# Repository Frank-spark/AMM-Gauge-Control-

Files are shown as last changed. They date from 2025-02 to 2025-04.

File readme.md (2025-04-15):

---
## **Project: ESP32 Gauge Control with H2 Integration**

### **Overview**
This project controls an **analog gauge** and **H2 power supply** using an **ESP32-WROOM-32D**. The gauge reflects the **fill level of a tank** based on readings from a **resistance-based float sensor (240Ω - 30Ω)**. The system implements a **soft-start feature** for H2 power supplies to prevent inrush current, and includes a **web configuration interface** for easy parameter adjustment.

### **Features**
✔ Reads **float sensor resistance** and converts it to gauge display using **PWM control**  
✔ **Smooths the gauge movement** to prevent needle shaking  
✔ **Blinks a backlight** when the fill level is low  
✔ **Soft-start control** (0-5V ramping) for H2 power supplies  
✔ **H2 signal detection** from existing H2 board  
✔ Uses **noise-filtered ADC readings** for reliable measurements  
✔ **Web-based configuration interface** for parameter adjustment  
✔ **WiFi connectivity** with fallback AP mode for setup  
✔ **Watchdog signal generation** (10ms interval)  
✔ **12V to 3.3V Buck Converter** power for ESP32  
✔ **12V to 5V Buck Converter** power for 5V components  

---

## **1. Hardware Setup**
### ** Components Needed**
- **ESP32-WROOM-32D**
- **Float Sensor (240Ω - 30Ω)**
- **10kΩ Pull-up Resistor** (for voltage divider)
- **Gauge (0-100% Analog Display)**
- **IRLB8721 MOSFET** (for PWM gauge control)
- **Level Shifter** (for 12V H2 signal input)
- **0-5V DAC/PWM Filter** (for power supply control)
- **330Ω Resistor + LED** (for backlight warning)
- **4-pin I2C Connector** (for future expansion)
- **2x 4.7kΩ Pull-up Resistors** (for I2C)
- **Watchdog Circuit** (connected to Pin 33)

### ** Wiring Guide**
#### **1️ Power Supply**
| Component | Connection |
|---|---|
| ESP32 VIN | **12V from H2 board gauge light** |
| ESP32 GND | **Common Ground** |
 12V to 5V Buck Converters:

#### **2️ Float Sensor (Resistance Measurement)**
| Pin | Connection |
|-----|---|
| **ESP32 GPIO 34** | **Voltage divider output** |
| **3.3V** | **10kΩ pull-up resistor** → Float Sensor |
| **GND** | **Float Sensor Ground** |

#### **3️ Gauge Control (PWM Output)**
| Pin | Connection |
|-----|---|
| **ESP32 GPIO 25** | **MOSFET Gate (IRLB8721)** |
| **Gauge (-)** | **MOSFET Drain** |
| **GND** | **MOSFET Source** |

#### **4️ Power Supply Control**
| Pin | Connection |
|-----|---|
| **ESP32 GPIO 27** | **PWM Filter** → Power Supply Control |
| **Power Supply CC** | **0-5V Control Input** |

#### **5️ H2 Signal Input**
| Pin | Connection |
|-----|---|
| **ESP32 GPIO 35** | **Level Shifter Output 10k and 39k VD** |
| **Level Shifter Input** | **H2 Board Coil Signal (12V)** |

#### **6️ Backlight Warning**
| Pin | Connection |
|-----|---|
| **ESP32 GPIO 26** | **LED via 330Ω Resistor** |
| **GND** | **LED Cathode (-)** |

#### **7️ I2C Expansion Port**
| Pin | Connection |
|-----|---|
| **1** | **3.3V** |
| **2** | **GPIO 21 (SDA) with 4.7kΩ pull-up** |
| **3** | **GPIO 22 (SCL) with 4.7kΩ pull-up** |
| **4** | **GND** |

#### **8️ Watchdog Signal Output**
| Pin | Connection |
|-----|---|
| **ESP32 GPIO 33** | **Watchdog Circuit Input** |

---

## **Power Supply Selection**

This project requires efficient **DC-DC buck converters** to step down **12V** to the required operating voltages (**5V** and **3.3V**). Below are the recommended surface-mount buck converters:

### **12V to 5V Buck Converters**
1. **Texas Instruments LM2675**  
   - Step-down voltage regulator with **1A** output.  
   - High efficiency, low component count.  
   - Ideal for powering microcontrollers and peripherals.  
   - [Datasheet](https://www.ti.com/lit/ds/symlink/lm2675.pdf)  

2. **Murata Power Solutions OKI-78SR-5/1.5-W36H-C**  
   - Drop-in replacement for traditional **78xx linear regulators**.  
   - Delivers **5V at up to 1.5A** with minimal heat dissipation.  
   - [Datasheet](https://power.murata.com/pub/data/power/oki-78sr.pdf)  

### **12V to 3.3V Buck Converters**
1. **Texas Instruments TPS54331**  
   - Integrated **3A** step-down regulator with **28V input capability**.  
   - Optimized for high efficiency in embedded systems.  
   - [Datasheet](https://www.ti.com/lit/ds/symlink/tps54331.pdf)  

2. **Analog Devices LTC3621**  
   - **1A synchronous buck converter** with **17V input capability**.  
   - Compact and energy-efficient for low-power applications.  
   - [Datasheet](https://www.analog.com/media/en/technical-documentation/data-sheets/LTC3621.pdf)  

### **Selection Considerations**
- **Current Requirements**: Choose a regulator based on the total current draw of your circuits.  
- **Efficiency**: Higher efficiency reduces heat and improves system stability.  
- **Footprint**: Ensure the selected components fit within the PCB layout.  
- **Availability**: Check supplier stock (e.g., [Digi-Key](https://www.digikey.com/) or [Mouser](https://www.mouser.com/)) before finalizing.  

## **2. Code Explanation**
### **⚙ Main Functionalities**
#### **1️ Setup Function**
- Initializes **PWM control for gauge and power supply**
- Sets up **GPIOs for backlight and H2 signal input**
- Starts **watchdog signal generation**
- Initializes **WiFi and web configuration server**

#### **2️ `loop()` Function**
- Monitors **H2 signal** for power control
- Reads **float sensor resistance**
- Controls **gauge display**
- Manages **power supply ramping**
- Handles **low-level warnings**
- Updates **watchdog signal**
- Processes **DNS requests** (in AP mode)

#### **3️ Power Supply Control**
```cpp
void startPEM() {
    // Ramps power supply control from 0V to max value
    for (current_ramp_value = 0; current_ramp_value <= pemMaxValue; current_ramp_value += pemStepSize) {
        ledc_set_duty(LEDC_LOW_SPEED_MODE, PS_PWM_CHANNEL, current_ramp_value);
        ledc_update_duty(LEDC_LOW_SPEED_MODE, PS_PWM_CHANNEL);
        delay(stepDelayMs);
    }
}
```

#### **4️ Read Float Sensor Resistance**
```cpp
float readFloatSensorResistance(int pin) {
    int adcValue = readSmoothADC(pin);
    float voltage = (adcValue / 4095.0) * 3.3;  

    if (voltage <= 0.1) return MAX_RESISTANCE;  

    float resistance = (voltage / (3.3 - voltage)) * knownResistor;
    return resistance;
}
```
- Uses **Ohm's Law** to convert voltage readings to **resistance (240Ω - 30Ω)**.
- **Failsafe:** If voltage is **too low**, assumes an **empty tank (240Ω).**

#### **5️ Smooth ADC Readings**
```cpp
int readSmoothADC(int pin) {
    int total = 0;
    for (int i = 0; i < numSamples; i++) {
        total += analogRead(pin);
        delayMicroseconds(500);
    }
    return total / numSamples;
}
```
- Averages **multiple ADC samples** to **reduce noise**.

#### **6️ Safety Handling**
- **Flashes backlight** when fill level is low
- **Shuts down power supply** by setting control voltage to 0V if level is critically low

#### **7️ Watchdog Signal Generation**
```cpp
void updateWatchdog() {
    unsigned long currentMillis = millis();
    
    // Only enable watchdog after a safe boot period
    if (!watchdogEnabled && (currentMillis - bootTime > WATCHDOG_ENABLE_DELAY)) {
        watchdogEnabled = true;
        Serial.println("Watchdog activated");
    }
    
    // Simply toggle the watchdog pin at the required interval
    if (watchdogEnabled && (currentMillis - lastWatchdogTime >= WATCHDOG_INTERVAL)) {
        lastWatchdogTime = currentMillis;
        digitalWrite(watch_dog, !digitalRead(watch_dog)); // Toggle
    }
}
```
- Generates a **10ms toggle signal** on Pin 33
- Delayed activation allows for **safe boot sequence**

---

## **3.1 Using the Web Configuration Interface**

### **Interface Layout and Navigation**
The web interface is organized into several sections for easy configuration:

1. **Header Section**: Shows the title "Gauge Control Configuration"
2. **Configuration Panels**: Grouped by function (Resistance, PWM, Timing, PEM, WiFi)
3. **Control Buttons**: Save configuration and reset to defaults
4. **Live Monitor**: Real-time data display from the gauge controller
5. **Status Messages**: Appear at the bottom when actions are performed

### **Step-by-Step Configuration Guide**

#### **Resistance Settings Adjustment**
These settings affect how the float sensor readings are interpreted:

1. **Max Resistance (Empty Tank)**: 
   - Default: 240Ω
   - Increase this value if your tank shows "empty" too early
   - Decrease if empty indication happens too late
   - Typical range: 200-300Ω

2. **Min Resistance (Full Tank)**:
   - Default: 30Ω
   - Increase if your tank shows "full" too soon
   - Decrease if the gauge never reaches full
   - Typical range: 20-50Ω

3. **Known Resistor**:
   - Default: 100Ω
   - This is the physical pull-up resistor value in your circuit
   - Only change if you've used a different resistor than specified

#### **PWM Settings Adjustment**
These settings control the gauge needle position:

1. **Min Duty (Empty)**: 
   - Default: 140
   - Controls gauge position when tank is empty
   - Lower value = gauge reads lower when empty
   - Adjust until gauge shows empty correctly

2. **Max Duty (Full)**:
   - Default: 255
   - Controls gauge position when tank is full
   - Higher value = gauge reads higher when full
   - Adjust until gauge shows full correctly

3. **Blink Threshold**:
   - Default: 10
   - Sets level for backlight blinking
   - Increase to start warning earlier (when tank is less empty)
   - Decrease to delay warning (when tank is more empty)

4. **Low Level Threshold**:
   - Default: 145
   - Below this level, power is cut to protect system
   - Should be higher than Blink Threshold but lower than normal operation

#### **PEM Startup Settings**
These settings control the power supply ramp behavior:

1. **Ramp Max Value**: 
   - Default: 255 (maximum PWM)
   - Controls final voltage sent to power supply (0-5V range)
   - Lower for reduced power output
   - Range: 0-255 (0-5V output)

2. **Ramp Step Size**:
   - Default: 1
   - Controls how quickly the voltage ramps up
   - Higher values = faster ramp (less smooth)
   - Lower values = slower ramp (smoother)
   - Recommended range: 1-5

3. **Step Delay**:
   - Default: 20ms
   - Time between voltage steps
   - Longer delay = slower, gentler startup
   - Shorter delay = faster startup
   - Total ramp time = (Max Value ÷ Step Size) × Step Delay

#### **WiFi Settings**
Configure network connectivity:

1. **WiFi SSID**: 
   - Enter your home/office network name
   - Leave blank to remain in AP mode

2. **WiFi Password**:
   - Enter password for your network
   - Will be securely stored in ESP32 memory

### **Using the Live Monitor**
The live monitor shows real-time system status:

- **Resistance**: Current reading from the float sensor (in ohms)
- **Target Duty**: Raw PWM value calculated from resistance
- **Smoothed Duty**: Actual PWM value sent to gauge (after smoothing)
- **PEM Status**: Shows if the power supply is running (green) or stopped (red)

### **Common Adjustments**

1. **Calibrating the Gauge**:
   - With tank empty: Adjust Min Duty until gauge reads empty
   - With tank full: Adjust Max Duty until gauge reads full
   - Fine-tune Min/Max Resistance if needed

2. **Adjusting Response Time**:
   - For faster gauge response: Decrease NORMAL_SMOOTHING in code
   - For smoother movement: Increase NORMAL_SMOOTHING in code
   - Default smoothing values provide good balance

3. **Customizing Power Ramp**:
   - For slower, gentler startup: Increase Step Delay and/or decrease Step Size
   - For faster startup: Decrease Step Delay and/or increase Step Size
   - For lower maximum power: Reduce Max Value

### **Saving and Resetting**

- **Save Configuration**: Click to store all settings in non-volatile memory
- **Reset to Defaults**: Reverts all settings to factory defaults
- Settings persist across power cycles once saved

### **Troubleshooting the Interface**

- **Changes not taking effect**: Ensure you clicked "Save Configuration"
- **Interface not loading**: Check WiFi connection or AP mode
- **Values resetting**: Possible memory corruption; try resetting to defaults
- **Gauge not responding to changes**: Check physical connections

## **3.2 Connecting to the Access Point**

### **Access Point Mode**
When the ESP32 can't connect to a configured WiFi network or no network is configured, it automatically starts in Access Point (AP) mode:

1. **AP Name**: `GaugeControl`
2. **AP Password**: `gaugeconfig`
3. **AP IP Address**: `192.168.4.1`

### **Connection Process**
1. **Power on the ESP32** controller
2. **Wait for initialization** (approximately 5 seconds)
3. **On your phone or computer**:
   - Open WiFi settings
   - Look for the `GaugeControl` network
   - Connect using password `gaugeconfig`
4. **Open a web browser** and navigate to:
   - `http://192.168.4.1`
   - The configuration interface should load automatically

### **Captive Portal**
The system uses a captive portal feature that will:
- Redirect all web requests to the configuration page
- Work similarly to hotel WiFi login pages
- On some devices, a login prompt may appear automatically

### **Station Mode (After Configuration)**
After configuring WiFi credentials and connecting to your network:
1. The ESP32 will connect to your WiFi network
2. The IP address is assigned by your router (DHCP)
3. Check your router's connected devices list to find the assigned IP
4. The serial monitor also displays the assigned IP address at startup

### **Switching Back to AP Mode**
If you need to reconfigure WiFi settings:
1. Power cycle the device 3 times in quick succession OR
2. If previously configured WiFi is unavailable, AP mode starts automatically

### **Troubleshooting Connection Issues**
- **AP not appearing**: Wait 30 seconds after power-on, then try again
- **Can't connect to AP**: Ensure you're using password `gaugeconfig`
- **Can't access 192.168.4.1**: Try disabling mobile data on your phone
- **Connection drops**: Stay within 15 feet (5 meters) of the ESP32

## **4. Expected Behavior**
| **Event** | **Action** | **Response** |
|---|---|---|
| **H2 Signal ON** | 12V on GPIO 35 | Start power supply ramp (configurable) |
| **H2 Signal OFF** | 0V on GPIO 35 | Immediate power supply shutdown |
| **Low Tank Level** | PWM < configurable threshold | Backlight starts blinking |
| **Normal Operation** | PWM > threshold | Normal gauge display |
| **Watchdog** | Continuous | 10ms toggle signal on Pin 33 |
| **Power on** | Boot sequence | AP mode if no WiFi configured |

---

## **5. Installation & Usage**
### ** Uploading Code**
1. Open **Arduino IDE**.
2. Install **ESP32 Board Support** via **Boards Manager**.
3. Install required libraries:
   - **ESPAsyncWebServer**
   - **AsyncTCP**
   - **ArduinoJson**
4. Connect **ESP32-WROOM-32D** to USB.
5. Upload `gaugecontrol.ino` and `webui.h`.

### **🔧 Adjusting Settings**
All settings can be adjusted via the web interface. Default values are:
```cpp
#define DEFAULT_MAX_RESISTANCE 240
#define DEFAULT_MIN_RESISTANCE 30
#define DEFAULT_KNOWN_RESISTOR 100
#define DEFAULT_MIN_DUTY 140
#define DEFAULT_MAX_DUTY 255
#define DEFAULT_BLINK_THRESHOLD 10
#define DEFAULT_LOW_LEVEL_THRESHOLD 145
#define DEFAULT_BLINK_INTERVAL 250
#define DEFAULT_NUM_SAMPLES 10
#define DEFAULT_STEP_DELAY_MS 20
#define DEFAULT_PEM_MAX_VALUE 255
#define DEFAULT_PEM_STEP_SIZE 1
```

---

## **6. Troubleshooting**
| **Issue** | **Possible Fix** |
|---|---|
| **Power supply not ramping** | Check PWM filter circuit and 0-5V output |
| **H2 signal not detected** | Verify level shifter operation and 12V input |
| **Gauge not moving** | Check MOSFET and PWM output |
| **Backlight issues** | Verify LED connections and GPIO 26 |
| **Repeated resets** | Check watchdog circuit and delay settings |
| **Can't access web interface** | Verify WiFi connection or AP mode |

---

## **7. Future Improvements**
🔹 Add **feedback monitoring** from power supply  
🔹 Implement **communication with H2 board**  
🔹 Add **diagnostic LED indicators**  
🔹 Add **I2C sensors or displays**  
🔹 Implement **I2C communication with external devices**  
🔹 Add **OTA firmware updates**  
🔹 Implement **data logging** to monitor system performance  

---

### **Final Notes**
- **This firmware controls an analog gauge, blinks a backlight for warnings, and manages a power supply ramp.**  
- **It provides a web interface for configuration and allows for WiFi connectivity.**
- **The watchdog implementation ensures reliability with external monitoring circuits.**
- **Ensure correct wiring for all circuits to prevent damage.**

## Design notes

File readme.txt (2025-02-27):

### **README for `gaugecontrol.cpp`**
---
## **Project: ESP32 Gauge Control with Float Sensor and Safety Cutoff**

### **Overview**
This project controls an **analog gauge** using an **ESP32-WROOM-32D**. The gauge reflects the **fill level of a tank**, based on readings from a **resistance-based float sensor (240Ω - 30Ω)**. It also features **a safety cutoff relay** and **a low-level warning backlight**.

### **Features**
✔ Reads **float sensor resistance** and converts it into a gauge display using **PWM control**.  
✔ **Smooths the gauge movement** to prevent needle shaking.  
✔ **Blinks a backlight** when the fill level is low.  
✔ **Cuts power (110V AC)** when the fill level is critically low.  
✔ Uses **noise-filtered ADC readings** for reliable measurements.

---

## **1. Hardware Setup**
### **🛠 Components Needed**
- **ESP32-WROOM-32D**
- **Float Sensor (240Ω - 30Ω)**
- **10kΩ Pull-up Resistor** (for voltage divider)
- **Gauge (0-100% Analog Display)**
- **IRLB8721 MOSFET** (for PWM gauge control)
- **110V Relay (Solid-State or Mechanical)**
- **PC817 Optocoupler** (for isolation)
- **2N2222 Transistor** (for relay control)
- **330Ω Resistor + LED** (for backlight warning)

### **🔌 Wiring Guide**
#### **1️⃣ Power Supply**
| Component | Connection |
|---|---|
| ESP32 3.3V | **3.3V Buck Converter** |
| ESP32 GND | **Common Ground** |

#### **2️⃣ Float Sensor (Resistance Measurement)**
| Pin | Connection |
|-----|---|
| **ESP32 GPIO 34** | **Voltage divider output** |
| **3.3V** | **10kΩ pull-up resistor** → Float Sensor |
| **GND** | **Float Sensor Ground** |

#### **3️⃣ Gauge Control (PWM Output)**
| Pin | Connection |
|-----|---|
| **ESP32 GPIO 25** | **MOSFET Gate (IRLB8721)** |
| **Gauge (-)** | **MOSFET Drain** |
| **GND** | **MOSFET Source** |

#### **4️⃣ 110V AC Power Cutoff**
| Pin | Connection |
|-----|---|
| **ESP32 GPIO 27** | **Relay Module Input** |
| **Relay NO Terminal** | **110V Load Line** |
| **Relay COM Terminal** | **110V Power** |

#### **5️⃣ Backlight Warning**
| Pin | Connection |
|-----|---|
| **ESP32 GPIO 26** | **LED via 330Ω Resistor** |
| **GND** | **LED Cathode (-)** |

---

## **2. Code Explanation**
### **⚙ Main Functionalities**
#### **1️⃣ Setup Function**
- Initializes **PWM control for the gauge**.
- Sets up **GPIOs for the backlight and power relay**.

#### **2️⃣ `loop()` Function**
- Reads **float sensor resistance** via **`readFloatSensorResistance()`**.
- Converts resistance into a **PWM signal** for the gauge.
- **Smooths gauge movement** to avoid sudden jumps.
- Calls **`manageSafety()`** to:
  - **Blink backlight** if level is low.
  - **Turn OFF power relay** if level is critically low.

#### **3️⃣ Read Float Sensor Resistance**
```cpp
float readFloatSensorResistance(int pin) {
    int adcValue = readSmoothADC(pin);
    float voltage = (adcValue / 4095.0) * 3.3;  

    if (voltage <= 0.1) return MAX_RESISTANCE;  

    float resistance = (voltage / (3.3 - voltage)) * KNOWN_RESISTOR;
    return resistance;
}
```
- Uses **Ohm’s Law** to convert voltage readings to **resistance (240Ω - 30Ω)**.
- **Failsafe:** If voltage is **too low**, assumes an **empty tank (240Ω).**

#### **4️⃣ Smooth ADC Readings**
```cpp
int readSmoothADC(int pin) {
    int total = 0;
    for (int i = 0; i < NUM_SAMPLES; i++) {
        total += analogRead(pin);
        delayMicroseconds(500);
    }
    return total / NUM_SAMPLES;
}
```
- Averages **10 ADC samples** to **reduce noise**.

#### **5️⃣ Safety Handling**
```cpp
void manageSafety(int pwmDuty) {
    unsigned long currentMillis = millis();

    if (pwmDuty < BLINK_THRESHOLD) {
        if (currentMillis - lastBlinkTime >= BLINK_INTERVAL) {
            lastBlinkTime = currentMillis;
            blinkState = !blinkState;
            digitalWrite(BACKLIGHT_PIN, blinkState);
        }
    } else {
        digitalWrite(BACKLIGHT_PIN, LOW);
    }

    if (pwmDuty < LOW_LEVEL_THRESHOLD) {
        Serial.println("KILL PIN ACTIVATED! Power Off!");
        digitalWrite(KILL_PIN, LOW);
    } else {
        digitalWrite(KILL_PIN, HIGH);
    }
}
```
- **Flashes backlight** when fill level is low.
- **Turns OFF 110V relay** if level is critically low.

---

## **3. Expected Behavior**
| **Tank Level (%)** | **Float Sensor Resistance (Ω)** | **PWM Duty (Gauge)** | **Backlight (GPIO 26)** | **Power Relay (GPIO 27)** |
|---|---|---|---|---|
| **100% (Full)** | 30Ω | 225 | OFF | ON (Power OK) |
| **50% (Half)** | 135Ω | 180 | OFF | ON (Power OK) |
| **20% (Low)** | 200Ω | 150 | **BLINKING** | ON (Power OK) |
| **5% (Critical)** | 240Ω | 140 | **BLINKING** | **OFF (Power Cut)** |

---

## **4. Installation & Usage**
### **📥 Uploading Code**
1. Open **Arduino IDE**.
2. Install **ESP32 Board Support** via **Boards Manager**.
3. Connect **ESP32-WROOM-32D** to USB.
4. Upload `gaugecontrol.cpp`.

### **🔧 Adjusting Settings**
- Change **gauge min/max values** in:
  ```cpp
  #define MIN_DUTY 140
  #define MAX_DUTY 225
  ```
- Adjust **low-level threshold**:
  ```cpp
  #define LOW_LEVEL_THRESHOLD 145
  ```
- Modify **safety cutoff temperature** (if thermistor is added later):
  ```cpp
  #define TEMP_THRESHOLD 60.0
  ```

---

## **5. Troubleshooting**
| **Issue** | **Possible Fix** |
|---|---|
| Gauge is **not moving** | Check if **PWM is set properly** in Serial Monitor (`PWM: X`). |
| Gauge **jumps suddenly** | Increase **smoothing factor** in `smoothedDuty = (0.05 * target) + (0.95 * smoothedDuty);` |
| Backlight **never blinks** | Verify **pwmDuty < 150** in `manageSafety()`. |
| Power **does not cut off** | Ensure **KILL_PIN (GPIO 27)** is correctly wired to the relay. |

---

## **6. Future Improvements**
🔹 Add **thermistor-based power cutoff** for temperature safety.  

---

### **Final Notes**
- **This firmware controls an analog gauge, blinks a backlight for warnings, and cuts power when necessary.**  
- **It operates on an ESP32 with ADC readings from a float sensor (240-30Ω) using a MOSFET for PWM control.**  
- **Ensure correct wiring for relay and MOSFET circuits to prevent damage.**

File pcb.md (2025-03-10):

### PCB Layout Description for Electrical Engineer

This board layout is designed to interface an ESP32-WROOM-32D with a float sensor (240-30Ω) and PWM-controlled gauge, while providing soft-start control (0-5V) for H2 power supplies. The system operates on 12V DC power from the H2 board's gauge light circuit.

* * *

## 1\. Power System

*   Input: 12V DC from H2 board gauge light
    
*   Voltage Regulation:
    *   Buck Converter (12V → 3.3V): Powers the ESP32
    *   Filtering Capacitors:
        *   100µF electrolytic (12V rail)
        *   10µF + 0.1µF ceramic (3.3V ESP32 supply)

* * *

## 2\. Float Sensor Interface (240-30Ω)

*   Voltage Divider Circuit:
    *   10kΩ Pull-up Resistor (3.3V → Sensor → ADC)
    *   Connects to GPIO 34 (ESP32 ADC Input)
    *   0.1µF ceramic capacitor for noise filtering
    *   Purpose: Converts sensor resistance to voltage readable by ESP32

* * *

## 3\. H2 Signal Input (12V)

*   Level Shifter Circuit:
    *   Input: 12V from H2 board coil signal
    *   Output: 3.3V to ESP32 GPIO 35
    *   Components:
        *   Voltage divider or dedicated level shifter IC
        *   10kΩ pull-down resistor on ESP32 input
        *   Protection diode for reverse voltage
    *   Purpose: Safely converts 12V H2 signal to 3.3V logic level

* * *

## 4\. Power Supply Control (0-5V Output)

*   PWM to Analog Circuit:
    *   Input: ESP32 GPIO 27 (PWM)
    *   Output: 0-5V DC to power supply CC input
    *   Components:
        *   RC low-pass filter (10kΩ + 10µF)
        *   Op-amp buffer (e.g., MCP6002)
        *   Precision voltage reference (optional)
    *   Purpose: Converts PWM to clean 0-5V control signal

* * *

## 5\. Gauge Control (PWM Output)

*   MOSFET Driver:
    *   MOSFET: IRLB8721 (N-channel, logic-level)
    *   10kΩ Pull-down Resistor (Gate to GND)
    *   1kΩ Series Resistor (ESP32 GPIO 25 → Gate)
    *   Gauge Ground (-) connects to MOSFET Drain
    *   Purpose: PWM control for smooth gauge movement

* * *

## 6\. Warning Indicator

*   LED Circuit:
    *   330Ω current-limiting resistor
    *   LED connected to GPIO 26
    *   Purpose: Visual warning for low tank level

* * *

## 7\. Future Expansion - I2C Interface

*   I2C Connector:
    *   4-pin header (3.3V, GND, SDA, SCL)
    *   Pin Assignment:
        *   GPIO 21: SDA
        *   GPIO 22: SCL
    *   Pull-up Resistors:
        *   2x 4.7kΩ resistors (one each for SDA and SCL)
    *   Protection:
        *   Optional TVS diodes for signal protection
    *   Connector Type:
        *   JST-XH or similar 2.54mm pitch header
        *   Keyed to prevent incorrect insertion

### Updated ESP32-WROOM-32D Pin Assignments

| ESP32 Pin | Function | Connected To |
|---|---|---|
| VIN | Power Input | 12V (via protection diode) |
| 3.3V | Regulated Power | 3.3V from Buck Converter |
| GND | Ground | Common Ground |
| GPIO 21 | I2C SDA | I2C Connector (with 4.7kΩ pullup) |
| GPIO 22 | I2C SCL | I2C Connector (with 4.7kΩ pullup) |
| GPIO 34 | ADC Input | Float Sensor Voltage Divider |
| GPIO 35 | Digital Input | H2 Signal (via level shifter) |
| GPIO 25 | PWM Output | Gauge MOSFET Gate |
| GPIO 27 | PWM Output | Power Supply Control Circuit |
| GPIO 26 | Digital Output | Warning LED |

### I2C Connector Pinout

```
1 - 3.3V
2 - SDA (GPIO 21)
3 - SCL (GPIO 22)
4 - GND
```

### PCB Layout Considerations for I2C

1. **Signal Routing:**
    * Keep I2C traces short and equal length
    * Route SDA and SCL close together
    * Avoid crossing noisy signals

2. **Pull-up Resistors:**
    * Place 4.7kΩ pull-ups near the ESP32
    * Use 0603 or 0805 package size

3. **Connector Placement:**
    * Edge-mounted for easy access
    * Away from power components
    * Clear labeling for pin 1

* * *

### Power Supply Control Circuit Detail

```
ESP32 GPIO 27 --[10kΩ]--+--[10µF]--GND
                        |
                        +--[Buffer Op-amp]---> To Power Supply CC
```

*   PWM Frequency: 10kHz
*   Filter cutoff: ~1.6Hz (for smooth ramping)
*   Output voltage range: 0-5V DC
*   Ramp time: 5 seconds (0 to full scale)

* * *

### PCB Layout Guidelines

1. **Power Distribution:**
    *   Separate ground planes for analog and digital
    *   Wide traces for 12V input
    *   Star ground configuration

2. **Signal Routing:**
    *   Keep analog signals away from PWM
    *   Short traces for ADC inputs
    *   Ground plane under level shifter

3. **Component Placement:**
    *   ESP32 module centrally located
    *   Power components near input
    *   Analog section isolated from digital

4. **Thermal Considerations:**
    *   Copper pour for MOSFET cooling
    *   Adequate ventilation for buck converter

5. **Protection Features:**
    *   Reverse polarity protection on 12V input
    *   TVS diodes on signal inputs
    *   Fuse for overcurrent protection

* * *

### Board Stack-up

*   2-layer board minimum
*   1oz copper recommended
*   FR4 material
*   Board size: Approximately 2" x 3"

* * *

### Testing Points

Include test points for:
*   12V input
*   3.3V regulated
*   H2 signal (both 12V and 3.3V sides)
*   Power supply control output
*   Float sensor input
*   Ground reference

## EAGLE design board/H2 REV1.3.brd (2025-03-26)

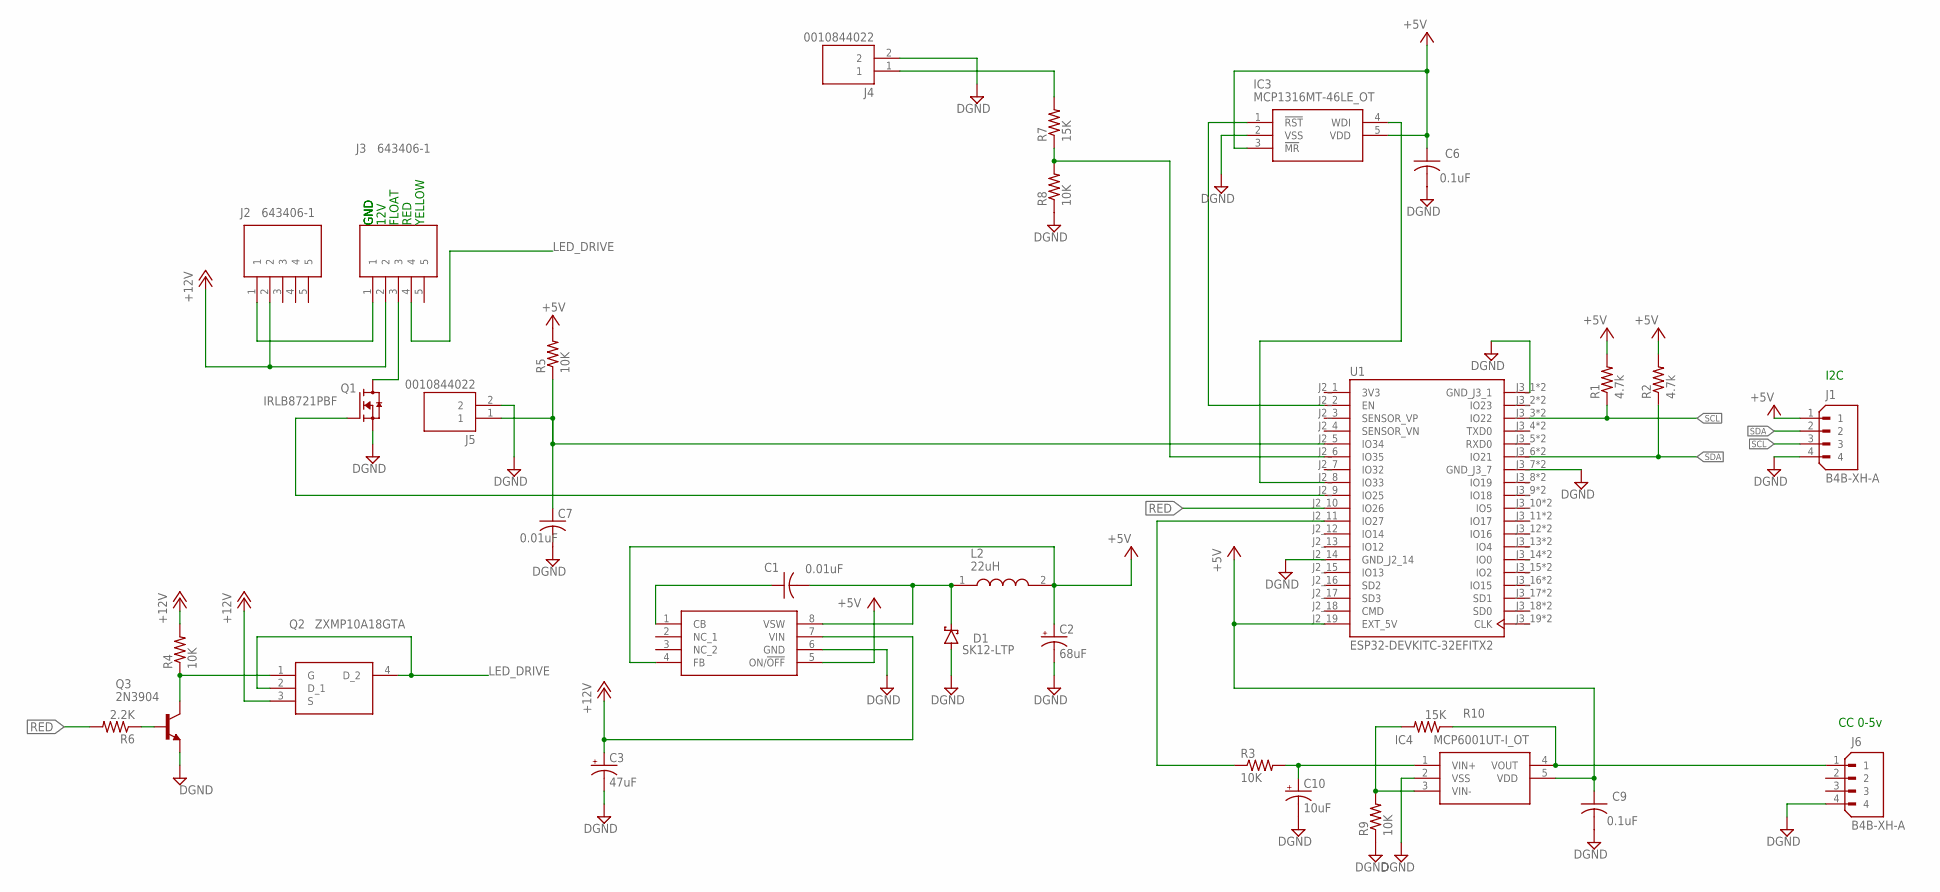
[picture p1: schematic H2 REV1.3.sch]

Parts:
C1, C7: 0.01uF; C0805
C2: 68uF; CT3528
C3: 47uF; CT7343
C6, C9: 0.1uF; C0805
C10: 10uF; CT7343
D1: SK12-LTP; SMB
IC2: LM2675M-5.0; SOIC127P600X175-8N
IC3: MCP1316MT-46LE_OT; SOT95P280X145-5N
IC4: MCP6001UT-I_OT; SOT95P280X145-5N
J1, J6: B4B-XH-A; JST_B4B-XH-A
J2, J3: 643406-1; 6434061
J4, J5: 0010844022; MOLEX_0010844022
L2: 22uH; 7447714220
Q1: IRLB8721PBF; TO254P1067X483X2057-3
Q2: ZXMP10A18GTA; SOT230P700X180-4N
Q3: 2N3904; SOT23-EBC
R1, R2: 4.7k; R0805
R3, R5, R8, R9: 10K; R0805
R4: 10K; M0805
R6: 2.2K; M0805
R7, R10: 15K; R0805
U1: ESP32-DEVKITC-32EFITX2; MODULE_ESP32-DEVKITC-32E

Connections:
3V3: U1.J2_1 (3V3)
+5V: C2.+, C6.1, C9.1, IC2.4 (FB), IC2.5 (ON/!OFF), IC3.3 (!MR), IC3.5 (VDD), IC4.5 (VDD), J1.1, L2.2, R1.2, R2.2, R5.2, U1.J2_19 (EXT_5V)
+12V: C3.+, IC2.7 (VIN), J2.2, J3.2, Q2.3 (S), R4.2
DGND: C2.-, C3.-, C6.2, C7.2, C9.2, C10.-, D1.A, IC2.6 (GND), IC3.2 (VSS), IC4.2 (VSS), J1.4, J4.2, J5.2, J6.4, Q1.3 (S), Q3.E, R8.1, R9.1, U1.J2_14 (GND_J2_14), U1.J3_1 (GND_J3_1), U1.J3_7 (GND_J3_7), U1.P$1 (GND_J3_1), U1.P$7 (GND_J3_7)
LED_DRIVE: J3.4, Q2.2 (D_1), Q2.4 (D_2)
unnamed: IC4.4 (VOUT), J6.1, R10.1
unnamed: Q1.1 (G), U1.J2_9 (IO25)
unnamed: J3.3, Q1.2 (D)
unnamed: C10.+, IC4.1 (VIN+), R3.2
unnamed: J4.1, R7.2
unnamed: C1.1, IC2.1 (CB)
unnamed: J2.1, J3.1
unnamed: C1.2, D1.C, IC2.8 (VSW), L2.1
unnamed: R7.1, R8.2, U1.J2_6 (IO35)
unnamed: IC3.1 (!RST), U1.J2_2 (EN)
unnamed: R3.1, U1.J2_11 (IO27)
unnamed: Q3.B, R6.1
unnamed: Q2.1 (G), Q3.C, R4.1
unnamed: C7.1, J5.1, R5.1, U1.J2_5 (IO34)
unnamed: IC3.4 (WDI), U1.J2_8 (IO33)
unnamed: IC4.3 (VIN-), R9.2, R10.2
RED: R6.2, U1.J2_10 (IO26)
SCL: J1.3, R1.1, U1.J3_3 (IO22), U1.P$3 (IO22)
SDA: J1.2, R2.1, U1.J3_6 (IO21), U1.P$6 (IO21)

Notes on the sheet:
I2C
CC 0-5v
GND
12V
FLOAT
RED
YELLOW

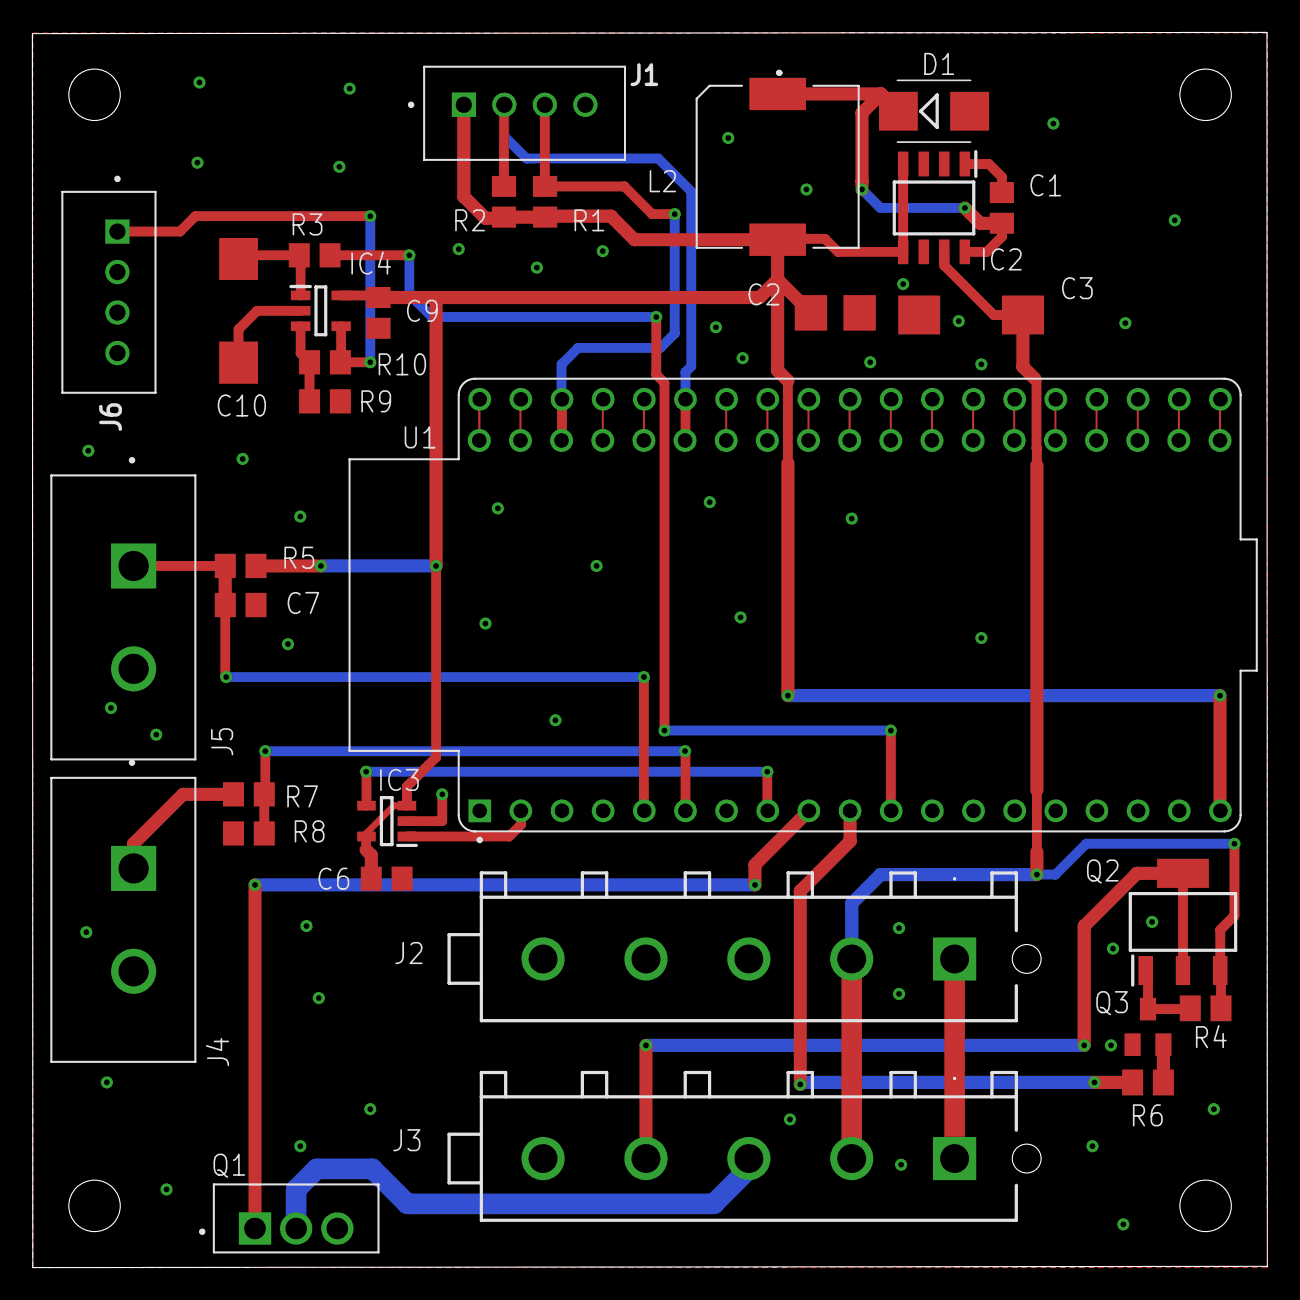
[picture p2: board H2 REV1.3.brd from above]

Board: 2 copper layers, 76.2 x 76.2 mm, 32 parts (0 on the bottom side), 23 nets.

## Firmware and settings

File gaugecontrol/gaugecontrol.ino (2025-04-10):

#include <Arduino.h>
#include "driver/ledc.h"  // Required for ESP32 Core v3.0.0+
#include <WiFi.h>
#include <ESPAsyncWebServer.h>
#include <AsyncTCP.h>
#include <ArduinoJson.h>
#include <Preferences.h>
#include <DNSServer.h>
#include "webui.h"

// Pin Definitions
#define MOSFET_PWM_PIN 25   // Controls gauge needle
#define BACKLIGHT_PIN 26    // Blinks when level is low
#define PS_CONTROL_PIN 27    // 0-5V control for power supply
#define FLOAT_SENSOR_PIN 34  // Reads float sensor voltage
#define H2_SIGNAL_PIN 35     // Input from H2 board coil plug (12V)
#define I2C_SDA_PIN 21        // I2C Data (reserved for future use)
#define I2C_SCL_PIN 22        // I2C Clock (reserved for future use)
#define watch_dog 33          // 10ms 

// PWM Configuration
#define PWM_FREQUENCY 5000  // PWM frequency in Hz
#define PWM_RESOLUTION LEDC_TIMER_8_BIT  // 8-bit for gauge control
#define PWM_CHANNEL LEDC_CHANNEL_0

// PWM Configuration for Power Supply Control
#define PS_PWM_FREQ 10000
#define PS_PWM_RES LEDC_TIMER_8_BIT
#define PS_PWM_CHANNEL LEDC_CHANNEL_1

// Float Sensor Resistance Range
#define MAX_RESISTANCE 240  // Ohms (Empty Tank)
#define MIN_RESISTANCE 30   // Ohms (Full Tank)
#define KNOWN_RESISTOR 100  // Changed from 10000 to 100 ohms

// PWM Range for Gauge
#define MIN_DUTY 140         // Empty
#define MAX_DUTY 255         // Full
#define BLINK_THRESHOLD 10  // If PWM < 150, blink BACKLIGHT_PIN
#define LOW_LEVEL_THRESHOLD 145  // Cut power if below this

#define BLINK_INTERVAL 250   // Blink time in milliseconds
#define NUM_SAMPLES 10       // Number of ADC samples for noise filtering
#define STEP_DELAY_MS 20     // Delay between power ramp steps (ms)

// Add these variables for watchdog timing
unsigned long lastWatchdogTime = 0;
#define WATCHDOG_INTERVAL 10   // 10ms interval

unsigned long lastBlinkTime = 0;
bool blinkState = false;
float smoothedDuty = MIN_DUTY; // Start at lowest gauge position

bool pem_running = false;
uint8_t current_ramp_value = 0;

// Increased smoothing factor for faster response
#define NORMAL_SMOOTHING 0.05  // Regular smoothing (5% of new value)
#define RECOVERY_SMOOTHING 0.25 // Faster smoothing when recovering from low level (25% of new value)
bool wasInLowLevel = false;    // Track if we were previously in low level

// WiFi Configuration
#define AP_SSID "GaugeControl"
#define AP_PASSWORD "gaugeconfig"
#define DNS_PORT 53

// Web server and DNS server
AsyncWebServer server(80);
DNSServer dnsServer;
Preferences preferences;

// WiFi mode flags
bool apMode = false;

// Configuration structure
struct Config {
  int maxResistance = 240;
  int minResistance = 30;
  int knownResistor = 100;
  int minDuty = 140;
  int maxDuty = 255;
  int blinkThreshold = 10;
  int lowLevelThreshold = 145;
  int blinkInterval = 250;
  int numSamples = 10;
  int stepDelay = 20;
  char wifiSSID[32] = "";
  char wifiPassword[64] = "";
  int pemMaxValue = 255;
  int pemStepSize = 1;
};

Config config;

// Variables to store current values for the web interface
float currentResistance = 0;
int currentTargetDuty = 0;

// Replace fixed #define values with variables
// Keep the #define for default values
#define DEFAULT_MAX_RESISTANCE 240
#define DEFAULT_MIN_RESISTANCE 30
#define DEFAULT_KNOWN_RESISTOR 100
#define DEFAULT_MIN_DUTY 140
#define DEFAULT_MAX_DUTY 255
#define DEFAULT_BLINK_THRESHOLD 10
#define DEFAULT_LOW_LEVEL_THRESHOLD 145
#define DEFAULT_BLINK_INTERVAL 250
#define DEFAULT_NUM_SAMPLES 10
#define DEFAULT_STEP_DELAY_MS 20

// Add default values
#define DEFAULT_PEM_MAX_VALUE 255
#define DEFAULT_PEM_STEP_SIZE 1

// Variables that will be modified at runtime
int maxResistance = DEFAULT_MAX_RESISTANCE;
int minResistance = DEFAULT_MIN_RESISTANCE;
int knownResistor = DEFAULT_KNOWN_RESISTOR;
int minDuty = DEFAULT_MIN_DUTY;
int maxDuty = DEFAULT_MAX_DUTY;
int blinkThreshold = DEFAULT_BLINK_THRESHOLD;
int lowLevelThreshold = DEFAULT_LOW_LEVEL_THRESHOLD;
int blinkInterval = DEFAULT_BLINK_INTERVAL;
int numSamples = DEFAULT_NUM_SAMPLES;
int stepDelayMs = DEFAULT_STEP_DELAY_MS;

// Add runtime variables
int pemMaxValue = DEFAULT_PEM_MAX_VALUE;
int pemStepSize = DEFAULT_PEM_STEP_SIZE;

// Add this near the other global variables
bool watchdogEnabled = false;
unsigned long bootTime = 0;
#define WATCHDOG_ENABLE_DELAY 5000 // 5 seconds delay before enabling watchdog

// Add this to your global variables
#define WIFI_CONNECT_TIMEOUT_MS 10000 // 10 second timeout for WiFi connection
hw_timer_t * watchdogTimer = NULL;
portMUX_TYPE timerMux = portMUX_INITIALIZER_UNLOCKED;

// Add this function to handle the hardware timer interrupt
void IRAM_ATTR onTimer() {
  portENTER_CRITICAL_ISR(&timerMux);
  digitalWrite(watch_dog, !digitalRead(watch_dog)); // Toggle the watchdog pin
  portEXIT_CRITICAL_ISR(&timerMux);
}

void setup() {
    Serial.begin(115200);
    Serial.println("Gauge Control System Starting...");
    
    // Record boot time
    bootTime = millis();
    
    // Configure watchdog pin as output and set it HIGH immediately to prevent reset
    pinMode(watch_dog, OUTPUT);
    digitalWrite(watch_dog, HIGH);
    
    // Reserve I2C pins for future use
    pinMode(I2C_SDA_PIN, INPUT);
    pinMode(I2C_SCL_PIN, INPUT);
    
    // Initialize WiFi and web server
    initWifi();

    // Configure PWM for Gauge Control
    ledc_timer_config_t timerConfig = {
        .speed_mode = LEDC_LOW_SPEED_MODE,
        .duty_resolution = PWM_RESOLUTION,
        .timer_num = LEDC_TIMER_0,
        .freq_hz = PWM_FREQUENCY,
        .clk_cfg = LEDC_AUTO_CLK
    };
    ledc_timer_config(&timerConfig);

    ledc_channel_config_t channelConfig = {
        .gpio_num = MOSFET_PWM_PIN,
        .speed_mode = LEDC_LOW_SPEED_MODE,
        .channel = PWM_CHANNEL,
        .intr_type = LEDC_INTR_DISABLE,
        .timer_sel = LEDC_TIMER_0,
        .duty = 0, // Initial duty cycle
        .hpoint = 0
    };
    ledc_channel_config(&channelConfig);

    // Configure PWM for Power Supply Control
    ledc_timer_config_t psTimerConfig = {
        .speed_mode = LEDC_LOW_SPEED_MODE,
        .duty_resolution = PS_PWM_RES,
        .timer_num = LEDC_TIMER_1,
        .freq_hz = PS_PWM_FREQ,
        .clk_cfg = LEDC_AUTO_CLK
    };
    ledc_timer_config(&psTimerConfig);

    ledc_channel_config_t psChannelConfig = {
        .gpio_num = PS_CONTROL_PIN,
        .speed_mode = LEDC_LOW_SPEED_MODE,
        .channel = PS_PWM_CHANNEL,
        .intr_type = LEDC_INTR_DISABLE,
        .timer_sel = LEDC_TIMER_1,
        .duty = 0,
        .hpoint = 0
    };
    ledc_channel_config(&psChannelConfig);

    // Setup Pins
    pinMode(BACKLIGHT_PIN, OUTPUT);
    pinMode(H2_SIGNAL_PIN, INPUT_PULLDOWN);
    digitalWrite(BACKLIGHT_PIN, LOW);

    // Initialize power supply control to 0V
    ledc_set_duty(LEDC_LOW_SPEED_MODE, PS_PWM_CHANNEL, 0);
    ledc_update_duty(LEDC_LOW_SPEED_MODE, PS_PWM_CHANNEL);

    Serial.println("System Initialized");
}

void loop() {
    // Handle DNS if in AP mode
    if (apMode) {
        dnsServer.processNextRequest();
    }
    
    // Handle watchdog signal
    updateWatchdog();

    // Check H2 signal
    bool h2_signal = digitalRead(H2_SIGNAL_PIN);

    // Handle PEM start/stop based on H2 signal
    if (h2_signal && !pem_running) {
        startPEM();
    } else if (!h2_signal && pem_running) {
        stopPEM();
    }

    // Read float sensor resistance
    float resistance = readFloatSensorResistance(FLOAT_SENSOR_PIN);
    currentResistance = resistance; // Store for web interface
    
    // Convert resistance to PWM duty cycle
    int targetDuty = map(resistance, maxResistance, minResistance, minDuty, maxDuty);
    currentTargetDuty = targetDuty; // Store for web interface
    
    // Use faster recovery when coming back from low level
    float smoothingFactor = (wasInLowLevel && targetDuty > BLINK_THRESHOLD) ? 
                            RECOVERY_SMOOTHING : NORMAL_SMOOTHING;
    
    // Smooth gauge movement with adaptive smoothing
    smoothedDuty = (smoothingFactor * targetDuty) + ((1.0 - smoothingFactor) * smoothedDuty);

    // Apply smoothed PWM duty cycle to gauge
    ledc_set_duty(LEDC_LOW_SPEED_MODE, PWM_CHANNEL, (int)smoothedDuty);
    ledc_update_duty(LEDC_LOW_SPEED_MODE, PWM_CHANNEL);

    // Track if we are/were in low level state
    bool isInLowLevel = ((int)smoothedDuty < BLINK_THRESHOLD);
    wasInLowLevel = isInLowLevel;

    // Handle low fill level conditions
    manageSafety((int)smoothedDuty);

    // Debug Output (shortened for simplicity)
    Serial.print("R: ");
    Serial.print(resistance);
    Serial.print(" | T: ");
    Serial.print(targetDuty);
    Serial.print(" | S: ");
    Serial.println((int)smoothedDuty);

    delay(50);
}

void startPEM() {
    Serial.println("Starting PEM - Ramping power supply");
    pem_running = true;
    
    // Ramp from 0 to max value using step size
    for (current_ramp_value = 0; current_ramp_value <= pemMaxValue; current_ramp_value += pemStepSize) {
        ledc_set_duty(LEDC_LOW_SPEED_MODE, PS_PWM_CHANNEL, current_ramp_value);
        ledc_update_duty(LEDC_LOW_SPEED_MODE, PS_PWM_CHANNEL);
        delay(stepDelayMs);
    }
    
    // Ensure we reach exactly the max value
    if (current_ramp_value > pemMaxValue) {
        ledc_set_duty(LEDC_LOW_SPEED_MODE, PS_PWM_CHANNEL, pemMaxValue);
        ledc_update_duty(LEDC_LOW_SPEED_MODE, PS_PWM_CHANNEL);
    }
}

void stopPEM() {
    Serial.println("Stopping PEM");
    pem_running = false;
    
    // Immediately set power supply control to 0
    ledc_set_duty(LEDC_LOW_SPEED_MODE, PS_PWM_CHANNEL, 0);
    ledc_update_duty(LEDC_LOW_SPEED_MODE, PS_PWM_CHANNEL);
    current_ramp_value = 0;
}

// Function to read float sensor resistance using a voltage divider
float readFloatSensorResistance(int pin) {
    int adcValue = readSmoothADC(pin);
    float voltage = (adcValue / 4095.0) * 3.3;  // Convert ADC to voltage
    
    if (voltage <= 0.1) return MAX_RESISTANCE;  // Default to empty if sensor fails

    // Use Ohm's law: R_sensor = (V / (3.3 - V)) * Known_Resistor
    float resistance = (voltage / (3.3 - voltage)) * knownResistor;
    return resistance;
}

// Function to filter ADC noise (Moving Average)
int readSmoothADC(int pin) {
    int total = 0;
    for (int i = 0; i < NUM_SAMPLES; i++) {
        total += analogRead(pin);
        delayMicroseconds(500);
    }
    return total / NUM_SAMPLES;
}

// Function to manage low-level conditions
void manageSafety(int pwmDuty) {
    unsigned long currentMillis = millis();

    // Blink Backlight if below threshold
    if (pwmDuty < blinkThreshold) {
        if (currentMillis - lastBlinkTime >= blinkInterval) {
            lastBlinkTime = currentMillis;
            blinkState = !blinkState;
            digitalWrite(BACKLIGHT_PIN, blinkState);
        }
    } else {
        // Reset blinking state and set backlight HIGH when above threshold
        blinkState = false;
        digitalWrite(BACKLIGHT_PIN, HIGH);
    }

    // If level is too low, shut down power supply by setting control voltage to 0
    if (pwmDuty < lowLevelThreshold) {
        Serial.println("Low level detected! Shutting down power supply.");
        ledc_set_duty(LEDC_LOW_SPEED_MODE, PS_PWM_CHANNEL, 0);
        ledc_update_duty(LEDC_LOW_SPEED_MODE, PS_PWM_CHANNEL);
        pem_running = false;
    }
}

void blinkBacklight() {
    unsigned long currentMillis = millis();
    if (currentMillis - lastBlinkTime >= blinkInterval) {
        lastBlinkTime = currentMillis;
        blinkState = !blinkState;
        digitalWrite(BACKLIGHT_PIN, blinkState);
    }
}

// Update the watchdog function
void updateWatchdog() {
    unsigned long currentMillis = millis();
    
    // Only enable watchdog after a safe boot period
    if (!watchdogEnabled && (currentMillis - bootTime > WATCHDOG_ENABLE_DELAY)) {
        watchdogEnabled = true;
        Serial.println("Watchdog activated");
    }
    
    // Simply toggle the watchdog pin at the required interval
    if (watchdogEnabled && (currentMillis - lastWatchdogTime >= WATCHDOG_INTERVAL)) {
        lastWatchdogTime = currentMillis;
        digitalWrite(watch_dog, !digitalRead(watch_dog)); // Toggle
    }
}

void initWifi() {
  preferences.begin("gauge-config", false);
  
  // Start a hardware timer to handle watchdog during WiFi connection
  watchdogTimer = timerBegin(0, 80, true); // Timer 0, divider 80 (1MHz)
  timerAttachInterrupt(watchdogTimer, &onTimer, true);
  timerAlarmWrite(watchdogTimer, 5000, true); // 5ms toggle (10ms period)
  timerAlarmEnable(watchdogTimer);

  // Load stored WiFi credentials
  if (preferences.getString("wifiSSID", "").length() > 0) {
    String ssid = preferences.getString("wifiSSID", "");
    String password = preferences.getString("wifiPassword", "");
    
    ssid.toCharArray(config.wifiSSID, sizeof(config.wifiSSID));
    password.toCharArray(config.wifiPassword, sizeof(config.wifiPassword));
    
    // Try to connect to stored WiFi with timeout
    WiFi.mode(WIFI_STA);
    WiFi.begin(config.wifiSSID, config.wifiPassword);
    
    Serial.print("Connecting to WiFi");
    
    unsigned long startTime = millis();
    while (WiFi.status() != WL_CONNECTED && millis() - startTime < WIFI_CONNECT_TIMEOUT_MS) {
      delay(100); // Shorter delay
      Serial.print(".");
      
      // Keep watchdog happy manually in addition to the timer
      digitalWrite(watch_dog, HIGH);
      delayMicroseconds(100);
      digitalWrite(watch_dog, LOW);
    }
    
    if (WiFi.status() == WL_CONNECTED) {
      Serial.println("");
      Serial.print("Connected to WiFi. IP: ");
      Serial.println(WiFi.localIP());
      apMode = false;
    } else {
      WiFi.disconnect();
      startAPMode();
    }
  } else {
    startAPMode();
  }
  
  // Disable the hardware timer once WiFi is connected
  timerAlarmDisable(watchdogTimer);
  timerDetachInterrupt(watchdogTimer);
  timerEnd(watchdogTimer);
  
  // Load other configuration values
  loadConfig();
  
  // Initialize web server
  initWebServer();
}

void startAPMode() {
  Serial.println("Starting AP mode");
  WiFi.mode(WIFI_AP);
  WiFi.softAP(AP_SSID, AP_PASSWORD);
  
  Serial.print("AP IP address: ");
  Serial.println(WiFi.softAPIP());
  
  // Start DNS server to redirect all domains to the captive portal
  dnsServer.start(DNS_PORT, "*", WiFi.softAPIP());
  
  apMode = true;
}

void loadConfig() {
  config.maxResistance = preferences.getInt("maxResistance", DEFAULT_MAX_RESISTANCE);
  config.minResistance = preferences.getInt("minResistance", DEFAULT_MIN_RESISTANCE);
  config.knownResistor = preferences.getInt("knownResistor", DEFAULT_KNOWN_RESISTOR);
  config.minDuty = preferences.getInt("minDuty", DEFAULT_MIN_DUTY);
  config.maxDuty = preferences.getInt("maxDuty", DEFAULT_MAX_DUTY);
  config.blinkThreshold = preferences.getInt("blinkThreshold", DEFAULT_BLINK_THRESHOLD);
  config.lowLevelThreshold = preferences.getInt("lowLevelThreshold", DEFAULT_LOW_LEVEL_THRESHOLD);
  config.blinkInterval = preferences.getInt("blinkInterval", DEFAULT_BLINK_INTERVAL);
  config.numSamples = preferences.getInt("numSamples", DEFAULT_NUM_SAMPLES);
  config.stepDelay = preferences.getInt("stepDelay", DEFAULT_STEP_DELAY_MS);
  config.pemMaxValue = preferences.getInt("pemMaxValue", DEFAULT_PEM_MAX_VALUE);
  config.pemStepSize = preferences.getInt("pemStepSize", DEFAULT_PEM_STEP_SIZE);
  
  // Update the runtime variables with loaded configuration
  maxResistance = config.maxResistance;
  minResistance = config.minResistance;
  knownResistor = config.knownResistor;
  minDuty = config.minDuty;
  maxDuty = config.maxDuty;
  blinkThreshold = config.blinkThreshold;
  lowLevelThreshold = config.lowLevelThreshold;
  blinkInterval = config.blinkInterval;
  numSamples = config.numSamples;
  stepDelayMs = config.stepDelay;
  pemMaxValue = config.pemMaxValue;
  pemStepSize = config.pemStepSize;
}

void saveConfig() {
  preferences.putInt("maxResistance", config.maxResistance);
  preferences.putInt("minResistance", config.minResistance);
  preferences.putInt("knownResistor", config.knownResistor);
  preferences.putInt("minDuty", config.minDuty);
  preferences.putInt("maxDuty", config.maxDuty);
  preferences.putInt("blinkThreshold", config.blinkThreshold);
  preferences.putInt("lowLevelThreshold", config.lowLevelThreshold);
  preferences.putInt("blinkInterval", config.blinkInterval);
  preferences.putInt("numSamples", config.numSamples);
  preferences.putInt("stepDelay", config.stepDelay);
  preferences.putInt("pemMaxValue", config.pemMaxValue);
  preferences.putInt("pemStepSize", config.pemStepSize);
  preferences.putString("wifiSSID", config.wifiSSID);
  preferences.putString("wifiPassword", config.wifiPassword);
  
  // Update the runtime variables with saved configuration
  maxResistance = config.maxResistance;
  minResistance = config.minResistance;
  knownResistor = config.knownResistor;
  minDuty = config.minDuty;
  maxDuty = config.maxDuty;
  blinkThreshold = config.blinkThreshold;
  lowLevelThreshold = config.lowLevelThreshold;
  blinkInterval = config.blinkInterval;
  numSamples = config.numSamples;
  stepDelayMs = config.stepDelay;
  pemMaxValue = config.pemMaxValue;
  pemStepSize = config.pemStepSize;
}

void initWebServer() {
  // Serve the main page
  server.on("/", HTTP_GET, [](AsyncWebServerRequest *request) {
    request->send_P(200, "text/html", index_html);
  });
  
  // Get current configuration
  server.on("/config", HTTP_GET, [](AsyncWebServerRequest *request) {
    String jsonResponse = getConfigJSON();
    request->send(200, "application/json", jsonResponse);
  });
  
  // Update configuration
  server.on("/config", HTTP_POST, [](AsyncWebServerRequest *request) {
    // Handle empty POST
    request->send(200, "application/json", "{\"status\":\"error\",\"message\":\"No data provided\"}");
  }, NULL, [](AsyncWebServerRequest *request, uint8_t *data, size_t len, size_t index, size_t total) {
    DynamicJsonDocument doc(1024);
    DeserializationError error = deserializeJson(doc, data, len);
    
    if (error) {
      request->send(400, "application/json", "{\"status\":\"error\",\"message\":\"Invalid JSON\"}");
      return;
    }
    
    // Update configuration
    config.maxResistance = doc["maxResistance"] | 240;
    config.minResistance = doc["minResistance"] | 30;
    config.knownResistor = doc["knownResistor"] | 100;
    config.minDuty = doc["minDuty"] | 140;
    config.maxDuty = doc["maxDuty"] | 255;
    config.blinkThreshold = doc["blinkThreshold"] | 10;
    config.lowLevelThreshold = doc["lowLevelThreshold"] | 145;
    config.blinkInterval = doc["blinkInterval"] | 250;
    config.numSamples = doc["numSamples"] | 10;
    config.stepDelay = doc["stepDelay"] | 20;
    config.pemMaxValue = doc["pemMaxValue"] | 255;
    config.pemStepSize = doc["pemStepSize"] | 1;
    
    // Handle WiFi credentials
    if (doc.containsKey("wifiSSID") && doc["wifiSSID"].as<String>().length() > 0) {
      strncpy(config.wifiSSID, doc["wifiSSID"].as<String>().c_str(), sizeof(config.wifiSSID) - 1);
      config.wifiSSID[sizeof(config.wifiSSID) - 1] = '\0';
    }
    
    if (doc.containsKey("wifiPassword")) {
      strncpy(config.wifiPassword, doc["wifiPassword"].as<String>().c_str(), sizeof(config.wifiPassword) - 1);
      config.wifiPassword[sizeof(config.wifiPassword) - 1] = '\0';
    }
    
    // Save configuration
    saveConfig();
    
    request->send(200, "application/json", "{\"status\":\"success\",\"message\":\"Configuration saved\"}");
  });
  
  // Reset to defaults
  server.on("/reset", HTTP_POST, [](AsyncWebServerRequest *request) {
    // Reset configuration to defaults
    config.maxResistance = 240;
    config.minResistance = 30;
    config.knownResistor = 100;
    config.minDuty = 140;
    config.maxDuty = 255;
    config.blinkThreshold = 10;
    config.lowLevelThreshold = 145;
    config.blinkInterval = 250;
    config.numSamples = 10;
    config.stepDelay = 20;
    config.pemMaxValue = 255;
    config.pemStepSize = 1;
    // Don't reset WiFi credentials
    
    saveConfig();
    
    String jsonResponse = getConfigJSON();
    request->send(200, "application/json", jsonResponse);
  });
  
  // Get live data
  server.on("/livedata", HTTP_GET, [](AsyncWebServerRequest *request) {
    char jsonBuffer[128];
    snprintf(jsonBuffer, sizeof(jsonBuffer), 
        "{\"resistance\":%.1f,\"targetDuty\":%d,\"smoothedDuty\":%d,\"pemRunning\":%s}", 
        currentResistance, currentTargetDuty, (int)smoothedDuty, pem_running ? "true" : "false");
    request->send(200, "application/json", jsonBuffer);
  });
  
  // Handle not found - redirect to root
  server.onNotFound([](AsyncWebServerRequest *request){
    request->redirect("/");
  });
  
  // Start server
  server.begin();
}

String getConfigJSON() {
  DynamicJsonDocument doc(1024);
  
  doc["maxResistance"] = config.maxResistance;
  doc["minResistance"] = config.minResistance;
  doc["knownResistor"] = config.knownResistor;
  doc["minDuty"] = config.minDuty;
  doc["maxDuty"] = config.maxDuty;
  doc["blinkThreshold"] = config.blinkThreshold;
  doc["lowLevelThreshold"] = config.lowLevelThreshold;
  doc["blinkInterval"] = config.blinkInterval;
  doc["numSamples"] = config.numSamples;
  doc["stepDelay"] = config.stepDelay;
  doc["pemMaxValue"] = config.pemMaxValue;
  doc["pemStepSize"] = config.pemStepSize;
  doc["wifiSSID"] = config.wifiSSID;
  doc["wifiPassword"] = ""; // Don't send the password to the client
  
  String jsonString;
  serializeJson(doc, jsonString);
  return jsonString;
}

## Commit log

2025-03-10 I2c added
2025-03-13 Update readme.md
    12v power stepdown selection
2025-03-26 submit board design
    [H2 REV1.3.brd, H2 REV1.3.sch]
